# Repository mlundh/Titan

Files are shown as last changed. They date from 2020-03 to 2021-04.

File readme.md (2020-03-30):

# Titan

Development board for robotics, drones and misc. projects. Initially designed to support [QuadSys](https://github.com/mlundh/QuadSys) development.

## Getting Started

These instructions will get you a copy of the project up and running on your local machine for development.

### Prerequisites

Install [KiCad](https://kicad-pcb.org/download/)

Example KiCad 5.1 for ubuntu:
```
sudo add-apt-repository --yes ppa:js-reynaud/kicad-5.1
sudo apt update
sudo apt install --install-recommends kicad
# If you want demo projects
sudo apt install kicad-demo
```
## Versioning

Each version I have manufactured is listed as a tag with only a version number in the repository.

Example:
```
v1.0
```
Each version that has been manufactured and verified will get tagged with vesion number and "_verified".

Example (does at time of writing this not exist):
```
v1.0_verified
```

## Authors

* **Martin Lundh** - [mlundh](https://github.com/mlundh)

## License

This project is licensed under the MIT License - see the [LICENSE.md](LICENSE.md) file for details

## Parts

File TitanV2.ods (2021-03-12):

Designator | nr | Designation
H2,H3,H4,H1 | 4 | MountingHole_Pad
C15,C28,C27,C18,C13,C12,C9,C8,C7,C6,C5,C4,C3 | 13 | 100nF
S1 | 1 | Reset button
U4 | 1 | CY15B104Q
J4 | 1 | Screw_Terminal_01x08
R21,R23,R22,R20 | 4 | 27
C24,C26,C25,C23 | 4 | 47pF
J1,J2 | 2 | USB_B_Micro
U6,U1 | 2 | FT230XS
U2 | 1 | ST732M33R
C1,C34,C33,C22,C16,C14 | 6 | 2.2uF
XTAL1 | 1 | NX3225GD-8MHZ-STD-CRA-3
U8,U5 | 2 | MPU-6050
U7 | 1 | XBEE3Micro
U3 | 1 | STM32F413VGTx
R72,R71,R69,R62,R61,R60,R59,R31,R30,R29,R28,R27,R26,R25,R24 | 15 | 10k
R70,R68 | 2 | 4,7k
R38 | 1 | 20k
R37,R33,R32,R14,R13,R12,R11,R10,R9,R3,R2 | 11 | 330
R36,R6 | 2 | 47k
R35,R34 | 2 | 4.7k
R15 | 1 | 100k
Q2,Q1 | 2 | NDS332P
J9,J8 | 2 | S3B-ZR(LF)(SN)
J5 | 1 | Debug
J3 | 1 | PWR CON
FB1 | 1 | Ferrite_Bead
D16 | 1 | LED
D15 | 1 | LED_Fatal_Error
D14 | 1 | LED_Error_Log
D13 | 1 | LED_Mode
D12 | 1 | LED_Status
D11 | 1 | LED_Valid_SP
D10 | 1 | LED_Heartbeat
D6,D4 | 2 | TXLED
D5,D3 | 2 | RXLED
D2,D1 | 2 | D_Schottky
C56,C32,C17 | 3 | 10nF
C55,C31,C21,C20,C11 | 5 | 0.1uF
C36,C30,C29 | 3 | 8.2pF
C35,C19 | 2 | 1uF
C10 | 1 | 10uF
 | 112

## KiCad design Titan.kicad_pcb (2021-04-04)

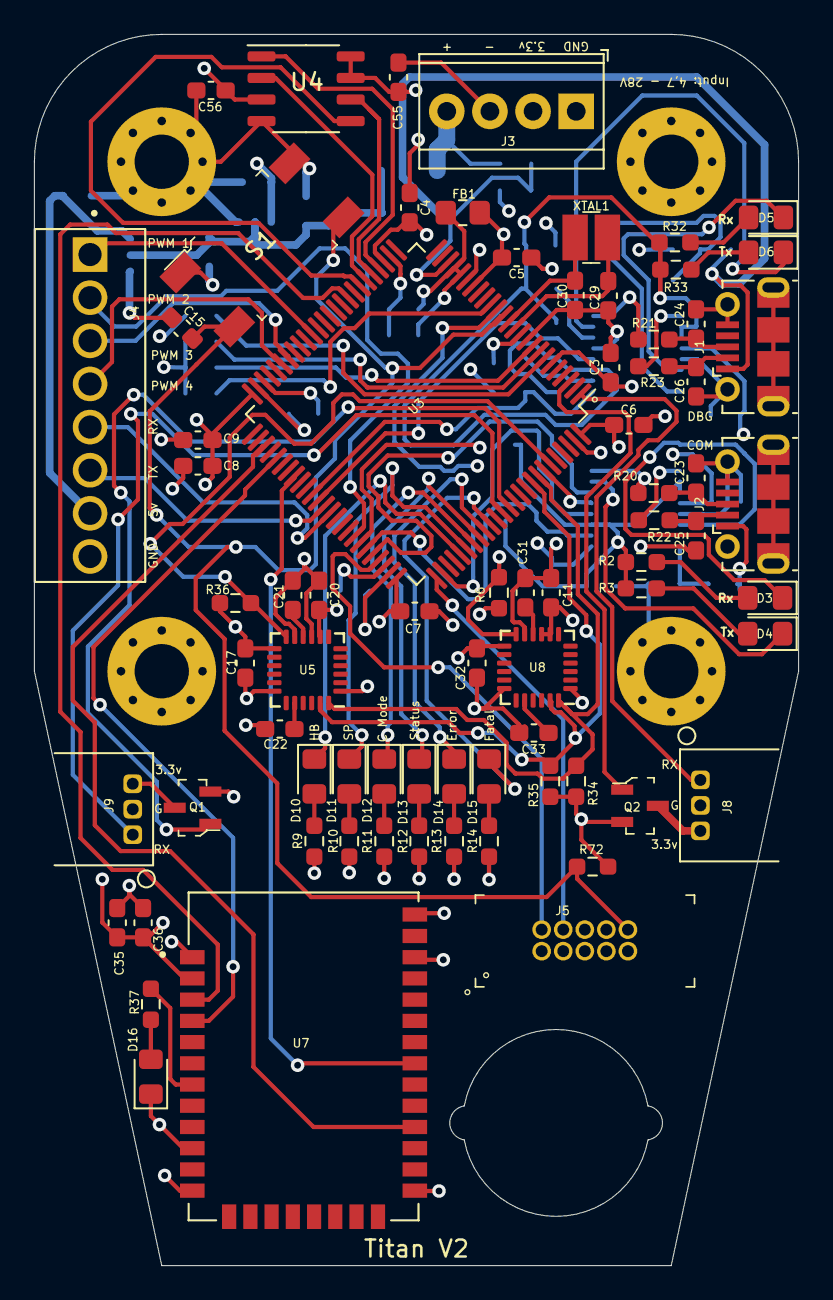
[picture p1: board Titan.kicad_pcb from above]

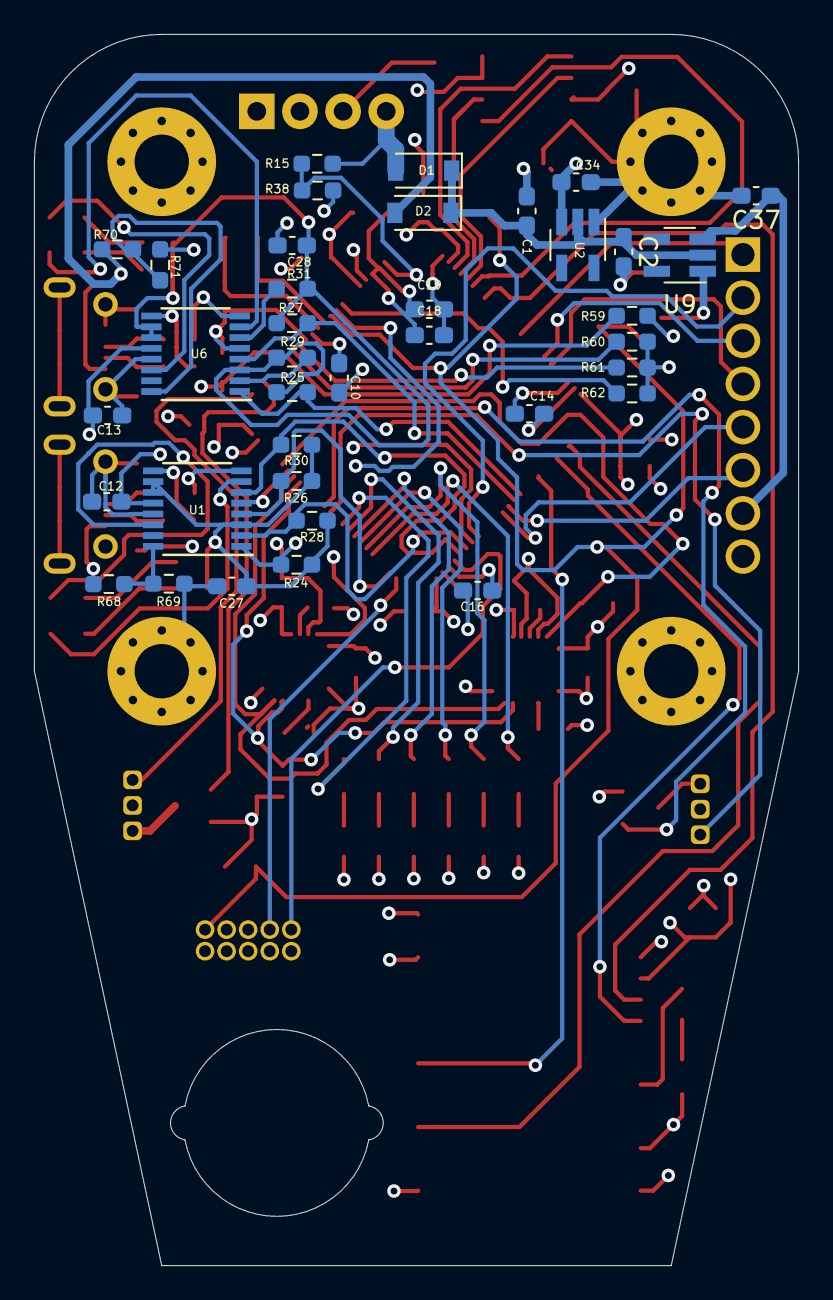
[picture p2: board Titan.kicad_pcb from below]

Board: 4 copper layers, 45.0 x 72.5 mm, 115 parts (37 on the bottom side), 90 nets.

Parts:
C1, C2, C14, C16, C22, C33, C34, C37: 2.2uF; C_0603_1608Metric_Pad1.08x0.95mm_HandSolder
C3, C4, C5, C6, C7, C8, C9, C12, C13, C15, C18, C27, C28: 100nF; C_0603_1608Metric_Pad1.08x0.95mm_HandSolder
C10: 10uF; C_0603_1608Metric_Pad1.08x0.95mm_HandSolder
C11, C20, C21, C31, C55: 0.1uF; C_0603_1608Metric_Pad1.08x0.95mm_HandSolder
C17, C32, C56: 10nF; C_0603_1608Metric_Pad1.08x0.95mm_HandSolder
C19, C35: 1uF; C_0603_1608Metric_Pad1.08x0.95mm_HandSolder
C23, C24, C25, C26: 47pF; C_0603_1608Metric_Pad1.08x0.95mm_HandSolder
C29, C30, C36: 8.2pF; C_0603_1608Metric_Pad1.08x0.95mm_HandSolder
D1, D2: D_Schottky; D_SOD-123
D3, D5: RXLED; LED_0805_2012Metric_Pad1.15x1.40mm_HandSolder
D4, D6: TXLED; LED_0805_2012Metric_Pad1.15x1.40mm_HandSolder
D10: LED_Heartbeat; LED_0805_2012Metric_Pad1.15x1.40mm_HandSolder
D11: LED_Valid_SP; LED_0805_2012Metric_Pad1.15x1.40mm_HandSolder
D12: LED_Status; LED_0805_2012Metric_Pad1.15x1.40mm_HandSolder
D13: LED_Mode; LED_0805_2012Metric_Pad1.15x1.40mm_HandSolder
D14: LED_Error_Log; LED_0805_2012Metric_Pad1.15x1.40mm_HandSolder
D15: LED_Fatal_Error; LED_0805_2012Metric_Pad1.15x1.40mm_HandSolder
D16: LED; LED_0805_2012Metric_Pad1.15x1.40mm_HandSolder
FB1: Ferrite_Bead; R_0805_2012Metric_Pad1.20x1.40mm_HandSolder
H1, H2, H3, H4: MountingHole_Pad; MountingHole_3.2mm_M3_Pad_Via
J1, J2: USB_B_Micro; USB_Micro-B_Molex-105017-0001
J3: PWR CON; TerminalBlock_TE_282834-4_1x04_P2.54mm_Horizontal
J4: Screw_Terminal_01x08; HDRV8W85P254_8X1_2078X650X1000
J5: Debug; PinHeader_2x5_P1.27mm_Drill.7mm
J8, J9: S3B-ZR(LF)(SN)
Q1, Q2: NDS332P; SOT-23-3
R2, R3, R9, R10, R11, R12, R13, R14, R32, R33, R37: 330; R_0603_1608Metric_Pad0.98x0.95mm_HandSolder
R6, R36: 47k; R_0603_1608Metric_Pad0.98x0.95mm_HandSolder
R15: 100k; R_0603_1608Metric_Pad0.98x0.95mm_HandSolder
R20, R21, R22, R23: 27; R_0603_1608Metric_Pad0.98x0.95mm_HandSolder
R24, R25, R26, R27, R28, R29, R30, R31, R59, R60, R61, R62, R69, R71, R72: 10k; R_0603_1608Metric_Pad0.98x0.95mm_HandSolder
R34, R35: 4.7k; R_0603_1608Metric_Pad0.98x0.95mm_HandSolder
R38: 20k; R_0603_1608Metric_Pad0.98x0.95mm_HandSolder
R68, R70: 4,7k; R_0603_1608Metric_Pad0.98x0.95mm_HandSolder
S1: Reset button; Switch_Tactile_SMD_6x6mm
U1, U6: FT230XS; SSOP-16_3.9x4.9mm_P0.635mm
U2: ST732M33R; SOT-23-5_HandSoldering
U3: STM32F413VGTx; LQFP-100_14x14mm_P0.5mm
U4: CY15B104Q; SOP-8_3.9x4.9mm_P1.27mm
U5, U8: MPU-6050; InvenSense_QFN-24_4x4mm_P0.5mm
U7: XBEE3Micro; XCVR_XB3-24Z8UM-J
U9: ST732M50R; SOT-23-5_HandSoldering
XTAL1: NX3225GD-8MHZ-STD-CRA-3; SMD-2_3.2x2.5mm

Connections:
+5V: C37.1, J4.7, U9.3
/ADC_BAT: R15.1, R38.2, U3.23
/I2C_SCL_IMU: R35.2, U3.92, U5.23, U8.23
/I2C_SDA_IMU: R34.2, U3.93, U5.24, U8.24
/IMU1_INT: R36.1, U3.95, U5.12
/IMU2_INT: R6.1, U3.15, U8.12
/LED_CTRL_MODE: D12.1, U3.82
/LED_ERROR: D14.1, U3.84
/LED_FATAL: D15.1, U3.85
/LED_HEARTBEAT: D10.1, U3.80
/LED_SETPOINT: D11.1, U3.81
/LED_STATUS: D13.1, U3.83
/PWM_1: J4.1, U3.40
/PWM_2: J4.2, U3.68
/PWM_3: J4.3, U3.44
/PWM_4: J4.4, U3.45
/RC_1_PWR_CTRL: Q2.1, U3.3
/RC_2_PWR_CTRL: Q1.1, U3.88
/REV1: R59.2, U3.7
/REV2: R60.2, U3.8
/REV3: R61.2, U3.9
/REV4: R62.2, U3.16
/SPI_MEM_MISO: U3.31, U4.2
/SPI_MEM_MOSI: U3.32, U4.5
/SPI_MEM_NSS: U3.29, U4.1
/SPI_MEM_SCK: U3.30, U4.6
/SWCLK: J5.4, U3.76
/SWDIO: J5.2, U3.72
/UART_COM_CTS: U3.58, U7.27
/UART_COM_RTS: U3.53, U7.24
/UART_COM_RX: U3.34, U7.3
/UART_COM_TX: U3.55, U7.4
/UART_COM_USB_CTS: R28.2, U1.2, U3.70
/UART_COM_USB_RTS: R30.2, U1.6, U3.71
/UART_COM_USB_RX: R24.2, U1.1, U3.69
/UART_COM_USB_TX: R26.2, U1.4, U3.77
/UART_DBG_RX: R25.2, U3.61, U6.1
/UART_DBG_TX: R27.2, U3.62, U6.4
/UART_MOTOR_2_RX: J4.5, U3.64
/UART_MOTOR_2_TX: J4.6, U3.63
/UART_RC_1_RX: J8.3, U3.1
/UART_RC_2_RX: J9.3, U3.87
/VBUS_COM: D2.2, J1.1, R70.1
/nRESET: C15.1, J5.10, R72.2, S1.3, S1.4, U3.14
GND: C1.2, C2.2, C3.2, C4.2, C5.2, C6.2, C7.2, C8.2, C9.2, C10.2, C11.1, C12.1, C13.1, C14.2, C15.2, C16.2, C17.1, C18.2, C19.2, C20.1, C21.2, C22.2, C23.2, C24.2, C25.2, C26.2, C27.1, C28.1, C29.2, C30.2, C31.2, C32.1, C33.2, C34.2, C35.2, C36.1, C37.2, C55.1, C56.1, D16.1, H1.1, H2.1, H3.1, H4.1, J1.5, J1.6, J2.5, J2.6, J3.1, J3.3, J4.8, J5.3, J5.5, J5.9, J8.2, J9.2, R38.1, R60.1, R61.1, R62.1, R69.2, R71.2, S1.1, S1.2, U1.5, U1.13, U2.1, U3.10, U3.20, U3.27, U3.49, U3.74, U3.94, U3.99, U4.4, U5.1, U5.9, U5.11, U5.18, U6.5, U6.13, U7.1, U7.10, U7.12, U7.21, U7.32, U7.34, U8.1, U8.11, U8.18, U9.1
unnamed: C1.1, C2.1, D1.1, D2.1, U2.2, U9.2
unnamed: C14.1, U3.48
unnamed: C16.1, U3.73
unnamed: C21.1, U5.10
unnamed: C22.1, U5.20
unnamed: C23.1, J2.3, R20.2
unnamed: C24.1, J1.3, R21.2
unnamed: C25.1, J2.2, R22.2
unnamed: C26.1, J1.2, R23.2
unnamed: C27.2, R2.1, R3.1, R24.1, R26.1, R28.1, R30.1, U1.3, U1.10, U1.11
unnamed: C28.2, R25.1, R27.1, R29.1, R31.1, R32.1, R33.1, U6.3, U6.10, U6.11
unnamed: C29.1, U3.12, XTAL1.1
unnamed: C30.1, U3.13, XTAL1.2
unnamed: C31.1, U8.10
unnamed: C33.1, U8.20
unnamed: D1.2, J3.4, R15.2
unnamed: D3.1, U1.14
unnamed: D3.2, R2.2
unnamed: D4.1, U1.7
unnamed: D4.2, R3.2
unnamed: D5.1, U6.14
unnamed: D5.2, R32.2
unnamed: D6.1, U6.7
unnamed: D6.2, R33.2
unnamed: D10.2, R9.2
unnamed: D11.2, R10.2
unnamed: D12.2, R11.2
unnamed: D13.2, R12.2
unnamed: D14.2, R13.2
unnamed: D15.2, R14.2
unnamed: D16.2, R37.2
unnamed: J2.1, R68.1
unnamed: J8.1, Q2.2
unnamed: J9.1, Q1.2
unnamed: R20.1, U1.8
unnamed: R21.1, U6.8
unnamed: R22.1, U1.9
unnamed: R23.1, U6.9
unnamed: R29.2, U6.2
unnamed: R31.2, U6.6
unnamed: R37.1, U7.7
unnamed: R68.2, R69.1, U1.16
unnamed: R70.2, R71.1, U6.16
VDDA_MCU: C18.1, C19.1, FB1.1, U3.21, U3.22
VDD_MCU: C3.1, C4.1, C5.1, C6.1, C7.1, C8.1, C9.1, C10.1, C11.2, C12.2, C13.2, C17.2, C20.2, C32.2, C34.1, C35.1, C36.2, C55.2, C56.2, FB1.2, J3.2, J5.1, Q1.3, Q2.3, R6.2, R9.1, R10.1, R11.1, R12.1, R13.1, R14.1, R34.1, R35.1, R36.2, R59.1, R72.1, U1.12, U2.3, U3.6, U3.11, U3.19, U3.28, U3.50, U3.75, U3.100, U4.3, U4.7, U4.8, U5.8, U5.13, U6.12, U7.2, U8.8, U8.9, U8.13

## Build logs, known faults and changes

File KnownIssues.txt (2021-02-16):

- Reset button always shorts to ground.
- Spectrum RC connector data should be on pin 1, is on pin 3.
- Spectrum RC power toggle mosfet S and D mixed up.

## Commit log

2020-03-29 Initial version of Titan board.
    [Titan.kicad_pcb, Titan.sch]
2021-02-16 First commit of TitanV2
    [Titan.kicad_pcb, Titan.sch]
2021-02-19 As ordered from Aisler.
    [Titan.kicad_pcb, Titan.sch]
2021-02-26 Update silkscreen.
    [Titan.kicad_pcb]
2021-03-12 Made the copper pour slightly smaller and removed it around the antenna mount. Also corrected some silkscreen print.
    [Titan.kicad_pcb, TitanV2.ods]
2021-04-04 Added a 5V regulator and connector. This will make it possible to power newer rc receivers.
    [Titan.kicad_pcb, Titan.sch]
